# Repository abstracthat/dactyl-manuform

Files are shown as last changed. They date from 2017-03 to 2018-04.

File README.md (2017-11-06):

# The Dactyl-ManuForm Keyboard
This is a fork of the [Dactyl](https://github.com/adereth/dactyl-keyboard), a parameterized, split-hand, concave, columnar, ergonomic keyboard.

Imgur

The main change is that the thumb cluster was adapted from the [ManuForm keyboard](https://github.com/jeffgran/ManuForm) ([geekhack](https://geekhack.org/index.php?topic=46015.0)). The walls were changed to just drop to the floor. The keyboard is paramaterized to allow adjusting the following: 

* Rows: 4 - 6 
* Columns: 5 and up
* Row curvature
* Column curvature
* Row tilt (tenting)
* Column tilt
* Column offsets
* Height

I built a 4x5 version (40% size) for myself. The default has a bit more tenting than the Dactyl. See the following model files for configurations that may be most common:

* [40% size, (4x5)](https://github.com/tshort/dactyl-keyboard/blob/master/things/right-4x5.stl)
* [60% size, (5x6)](https://github.com/tshort/dactyl-keyboard/blob/master/things/right-5x6.stl)

## Assembly

### Generating a Design

**Setting up the Clojure environment**
* [Install the Clojure runtime](https://clojure.org)
* [Install the Leiningen project manager](http://leiningen.org/)
* [Install OpenSCAD](http://www.openscad.org/)

**Generating the design**
* Run `lein repl`
* Load the file `(load-file "src/dactyl_keyboard/dactyl.clj")`
* This will regenerate the `things/*.scad` files
* Use OpenSCAD to open a `.scad` file.
* Make changes to design, repeat `load-file`, OpenSCAD will watch for changes and rerender.
* When done, use OpenSCAD to export STL files

**Tips**
* [Some other ways to evaluate the clojure design file](http://stackoverflow.com/a/28213489)
* [Example designing with clojure](http://adereth.github.io/blog/2014/04/09/3d-printing-with-clojure/)

### Printing
Pregenerated STL files are available in the [things/](things/) directory. 
When a model is generated, it also generates a `.scad` model for a bottom plate. 
This can be exported to a DXF file in OpenSCAD.
The [things/](things/) directory also has DXF files for the bottom plate.
When laser cut, some of the inside cuts will need to be removed. 

This model can be tricky to print. 
It's wide, so I've had problems with PLA on a Makerbot with edges warping. 
This can cause the printer to think its head is jammed. 
Even if it successfully prints, warping can cause problems. 
On one print, the RJ-9 holder was squished, so I had to cut down my connector to fit.

If printed at Shapeways or other professional shops, I would not expect such problems. 

### Thingiverse

[The 4x5 STL left/right pair](https://www.thingiverse.com/thing:2349390) from the [things/](things/) directory is in the thingiverse for public printing

### Wiring

Here are materials I used for wiring.

* Two Arduino Pro Micros
* [Heat-set inserts](https://www.mcmaster.com/#94180a331/=16yfrx1)
* [M3 wafer-head screws, 5mm](http://www.metricscrews.us/index.php?main_page=product_info&cPath=155_185&products_id=455)
* [Copper tape](https://www.amazon.com/gp/product/B009KB86BU)
* [#32 magnet wire](https://www.amazon.com/gp/product/B00LV909HI)
* [#30 wire](https://www.amazon.com/gp/product/B00GWFECWO)
* [3-mm cast acrylic](http://www.mcmaster.com/#acrylic/=144mfom)
* [Veroboard stripboard](https://www.amazon.com/gp/product/B008CPVMMU)
* [1N4148 diodes](https://www.amazon.com/gp/product/B00LQPY0Y0)
* [Female RJ-9 connectors](https://www.amazon.com/gp/product/B01HU7BVDU/)

I wired one half using the traditional approach of using the legs of a diode to form the row connections. 
(I'm not great at soldering, so this was challenging for me.)
For this side, I used magnet wire to wire columns. That worked okay. 
The magnet wire is small enough, it wants to move around, and it's hard to tell if you have a good connection.

Imgur

For another half, I used stripboard for the row connections. 
This allowed me to presolder all of the diodes. 
Then, I hot-glued this in place and finished the soldering of the other diode ends. 
I like this approach quite a lot. 
Connections for the diodes were much easier with one end fixed down. 
On this half, I also used copper tape to connect columns. 
This worked a bit better than the magnet wire for me. 
For a future version, I may try just bare tinned copper wire for columns (something like #20). 
With the stripboard, it's pretty easy keeping row and column connections separate.

Imgur

Note that a telephone handset cable has leads that are reversed, so take this into account when connecting these leads to the controller.

The 3D printed part is the main keyboard. 
You can attach a bottom plate with screws. 
The case has holes for heat-set inserts designed to hold 3- to 6-mm long M3 screws. 
Then, I used wafer-head screws to connect a bottom plate. 
If wires aren't dangling, a bottom plate may not be needed. 
You need something on the bottom to keep the keyboard from sliding around. 
Without a plate, you could use a rubber pad, or you could dip the bottom of the keyboard in PlastiDip.

For more photos of the first complete wiring of v0.4, see [Imgur](http://imgur.com/a/v9eIO).

This is how the rows/columns wire to the keys and the ProMicro
Wire Diagram

#### Alternative row-driven wiring diagram for ProMicro:

NOTE: you also make sure the firmware is set up correctly (ex: change row pins with col pins)

Left Wire Diagram

Left Wire Diagram


### Firmware

Firmware goes hand in hand with how you wire the circuit. 
I adapted the QMK firmware [here](https://github.com/tshort/qmk_firmware/tree/master/keyboards/dactyl-manuform). 
This allows each side to work separately or together. 
This site also shows connections for the Arduino Pro Micro controllers.

## License

Copyright © 2015-2017 Matthew Adereth and Tom Short

The source code for generating the models (everything excluding the [things/](things/) and [resources/](resources/) directories is distributed under the [GNU AFFERO GENERAL PUBLIC LICENSE Version 3](LICENSE).  The generated models and PCB designs are distributed under the [Creative Commons Attribution-NonCommercial-ShareAlike License Version 3.0](LICENSE-models).

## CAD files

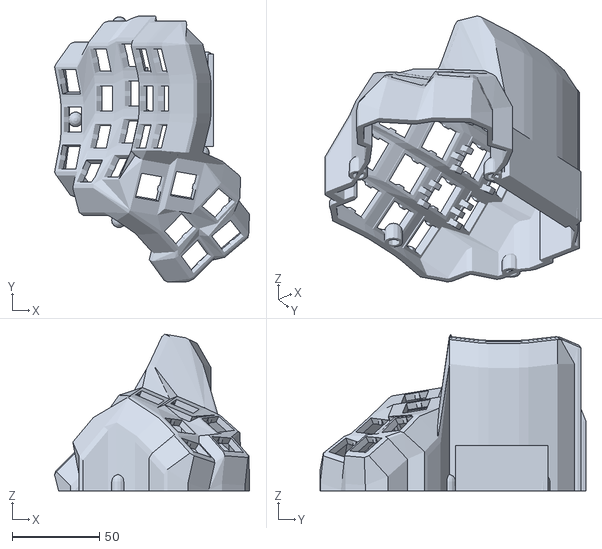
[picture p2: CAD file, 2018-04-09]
things/left.stl
111.8 x 152.3 x 89.8

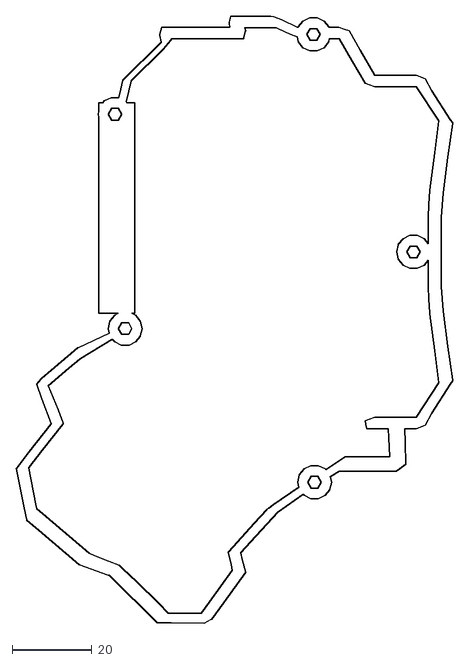
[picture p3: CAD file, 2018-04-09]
things/right-plate.dxf
109.4 x 152.3

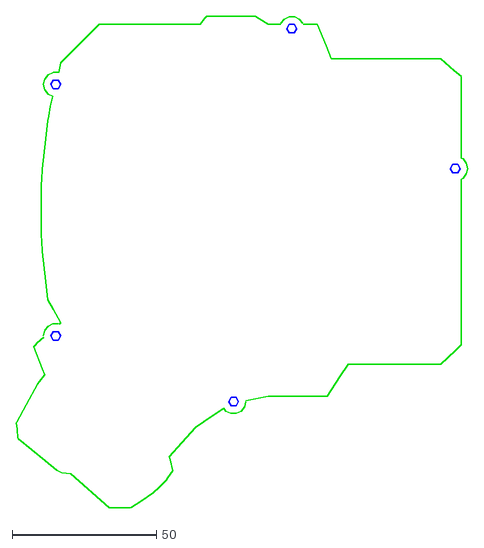
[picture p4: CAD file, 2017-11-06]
things/right-5x6-plate-ready-to-cut.dxf
156.5 x 170.5

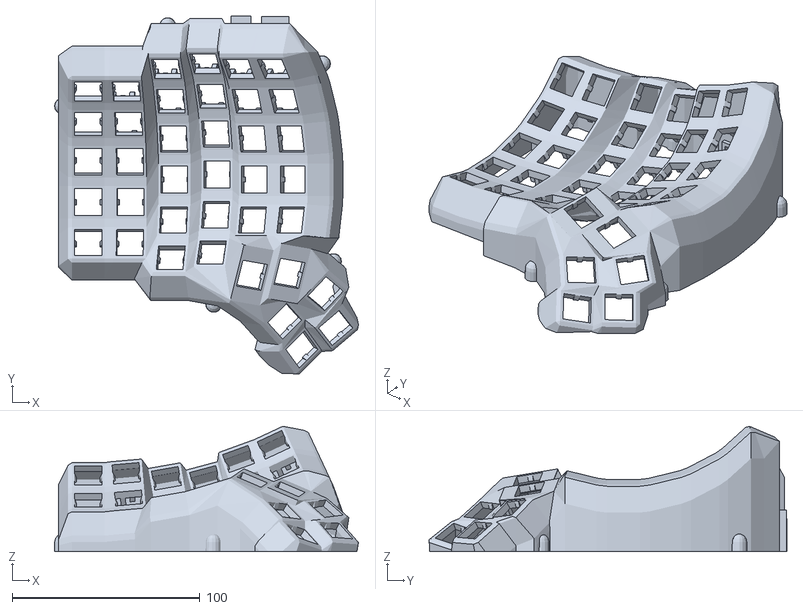
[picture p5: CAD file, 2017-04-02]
things/left-6x6.stl
161.7 x 190.2 x 66.8

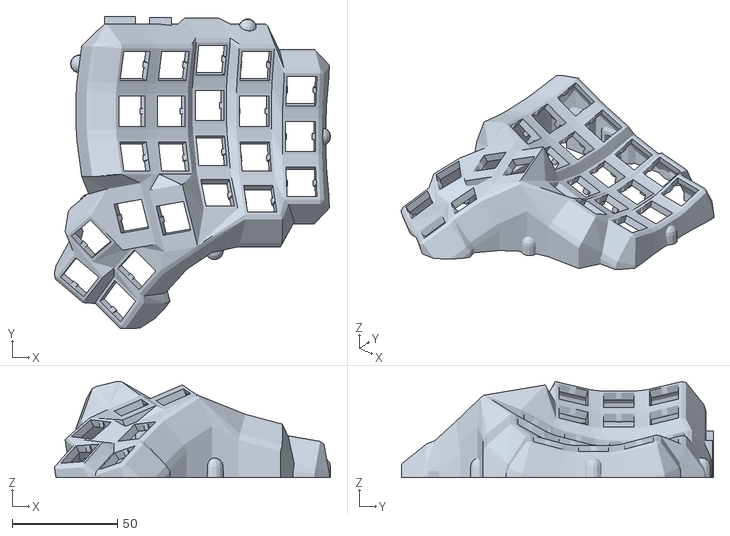
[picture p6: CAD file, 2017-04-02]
things/right-4x5.stl
131.5 x 148.4 x 45.8

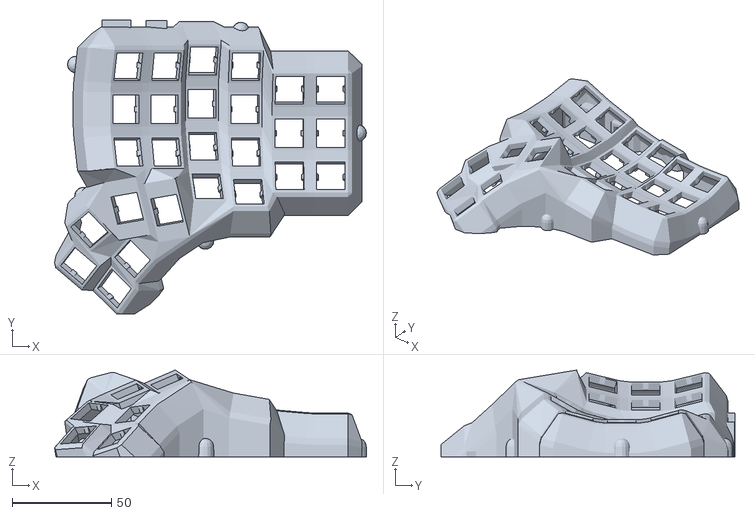
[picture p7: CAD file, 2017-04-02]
things/right-4x6.stl
157.2 x 148.4 x 43.8

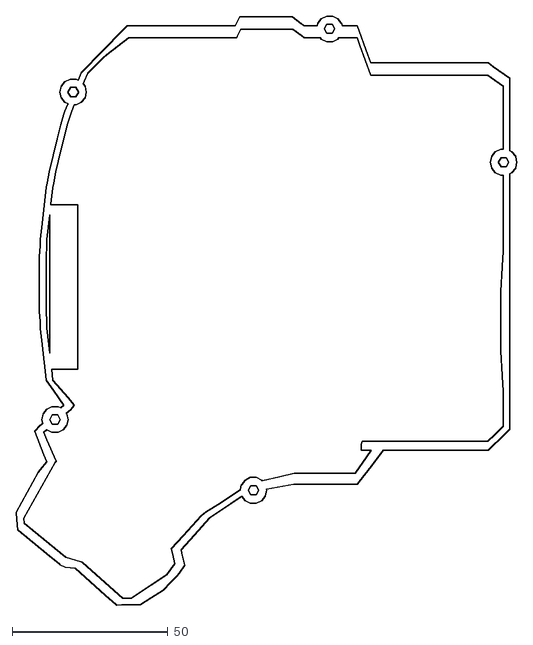
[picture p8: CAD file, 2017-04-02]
things/right-6x6-plate.dxf
160.9 x 189.3

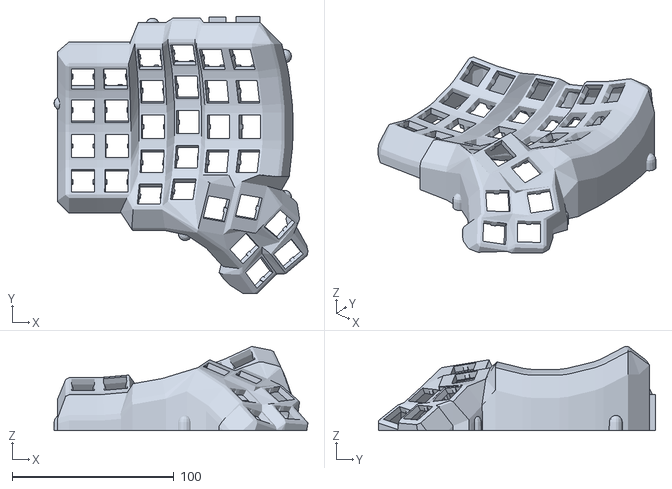
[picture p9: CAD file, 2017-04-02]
things/left-5x6.stl
157.2 x 171.5 x 52.1

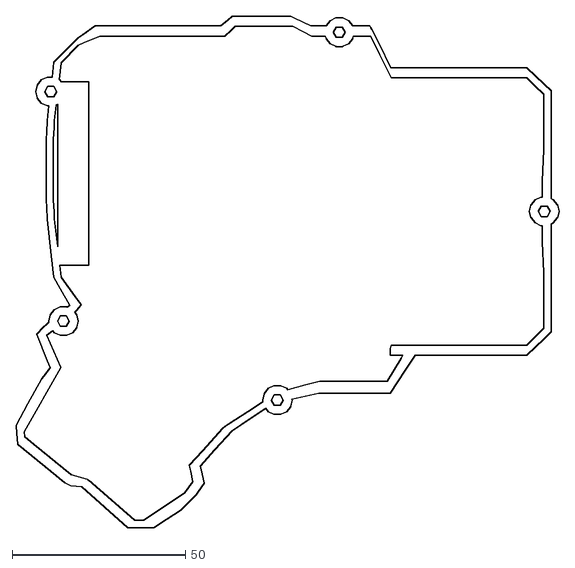
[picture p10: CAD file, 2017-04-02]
things/right-4x6-plate.dxf
156.5 x 147.5

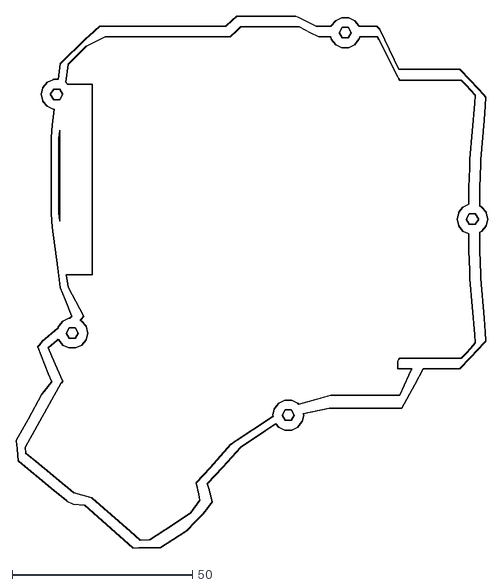
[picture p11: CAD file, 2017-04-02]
things/right-4x5-plate.dxf
130.7 x 147.5

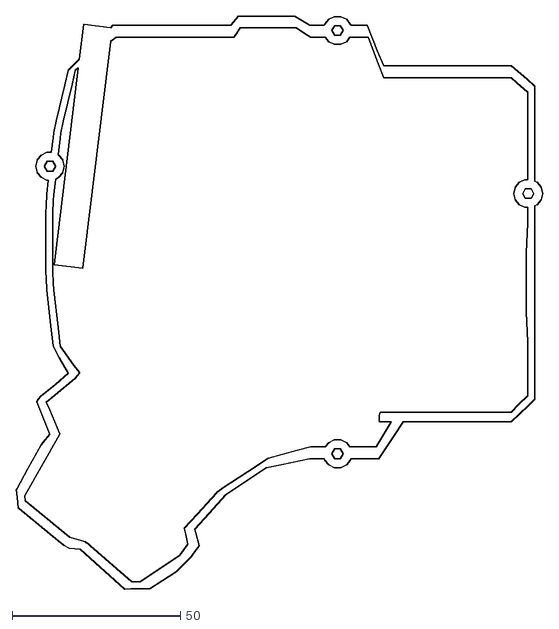
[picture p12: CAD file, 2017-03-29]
things/right-5x6-plate.dxf
156.5 x 170.5

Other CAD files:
things/right.stl
things/left-4x6.stl
things/left-4x5.stl
things/right-5x6.stl
things/right-6x6.stl

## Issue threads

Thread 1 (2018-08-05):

Variable commented out that are used in the code

impaktor, 2018-08-05:
This block:
```clojure
;; Settings for column-style == :fixed
;; The defaults roughly match Maltron settings
;;   http://patentimages.storage.googleapis.com/EP0219944A2/imgf0002.png
;; Fixed-z overrides the z portion of the column ofsets above.
;; NOTE: THIS DOESN'T WORK QUITE LIKE I'D HOPED.
(def fixed-angles [(deg2rad 10) (deg2rad 10) 0 0 0 (deg2rad -15) (deg2rad -15)])
(def fixed-x [-41.5 -22.5 0 20.3 41.4 65.5 89.6])  ; relative to the middle finger
(def fixed-z [12.1    8.3 0  5   10.7 14.5 17.5])
(def fixed-tenting (deg2rad 0))
```
...is commented out in master, and have been since commit a4014a25713525267846ce10188343bf9ddfe6fa. Without it, the code will not run to generate *.scad files.

irrenhaus, 2018-08-14:
Can confirm this @abstracthat.

Just cloned the project and wanted to build it but it turned out that the compiler gave an error.
Luckily this issue was opened, so I was able to resolve it by uncommenting these variables.

impaktor, 2018-08-14:
@irrenhaus I would recommend cloning (or forking) the original dactyl manuform mod instead, which is by @tshort, [here](https://github.com/tshort/dactyl-keyboard)

If you check the commit history, @adereth did the original, @tshort did the Dactyl Manuform, but as a branch of his fork, and this repo just renamed the project to the same name as tshort's branch. Quite confusing. Or at least that's how I interpret it.

This repo is the one that is linked from the geekhack main Dactyl Manuform thread. I think it should link to tshort's repo instead.

(I'll be doing a PLA 3D print of this tomorrow, so we'll see how it turns out.)

irrenhaus, 2018-08-16:
@impaktor Oh thanks a bunch! I think I got to this repository through google, so maybe it's just ranked up higher than the correct repository there.

impaktor, 2018-08-16:
@irrenhaus no problem. I've opened a pull request on tshorts repo, also saving out the swich hole for test printing. It looks to me like what this repo (abstracthat) went for was a 90 degree vertical stagger.

abstracthat, 2018-08-16:
Hi guys. Didn't mean to deceive anyone this is indeed just a fork.

And I haven't printed it but would like to. I don't remember breaking the compile though as I had open scad running while l was tweaking. But it's certainly possible!

It is a very large tenting angle (I use a split Mitosis keyboard on 55degree wood blocks at the moment which I like a lot). I also messed with where the thumb keys sit and I started to move the screws for the bottom plate because they don't line up quite right when the footprint is changed so much for the large tenting.

impaktor, 2018-08-17:
> Hi guys. Didn't mean to deceive anyone this is indeed just a fork.

Yeah, sorry, I didn't mean to come off like I'm implying that.

> It is a very large tenting angle

I wonder if a hollow keyboard has enough friction to the surface to be used at 90-degree angle?

Some of the tweeks I'm aiming to implement on my fork is to re-import the original TRRS jack, instead of the RJ9 connector. I'm currently just where I need to figure out how to move the TRRS hole to where I want it.

Also, Alps/Matias switch holes would be nice, which is also something I'll play around with.

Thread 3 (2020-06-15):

types of switches

shiftux, 2020-06-15:
hello,
this project looks amazing! thanks for all the work! - i'm planning on making one!
i'd like to understand the compatibility with different switch manufacturers...
thinking of Cherry, Kailh, Gateron, ...
Could someone make a statement about what would fit?
or is it possible to customize the switch sockets (like explained here https://github.com/adereth/dactyl-keyboard/issues/56#issuecomment-376463735) ?

thanks for your insights

BobLoblaw5, 2020-06-21:
I just built one using gateron browns and I know cherry switches will work as well.  Not as familiar with Kailh but I would think that any Mx style switch should work.

shiftux, 2020-07-07:
the answer here is yes, they do work.
but indeed you need to modify the switch sockets, you'll want to remove the "side-nub" in the clojure files

Closed 2020-07-07.

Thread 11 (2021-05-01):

Kailh incompatibility

flowswitch, 2021-05-01:
A little warning for fellow builders planning to use Kailh switches: the side locking tabs are incompatible with Kailhs (those have no side notches matching them). A switch could be forced into position, but it will tend to jump out. Either remove the tabs from the model before printing or cut them with shears after (that was my case, discovered the problem after printing).
Other types of switches I’ve tested are Gateron and Everglide - both fits perfectly (they follow Cherry MX shape I guess).

suryanisaac, 2021-07-27:
Hey! Thanks for the heads up - I was planning to use Kailh switches.

Do you know of any forks/versions without the tabs?

flowswitch, 2021-07-27:
Unfortunately no. Found the problem after printing so the question was how to fix the already printed part.

suryanisaac, 2021-07-28:
Thank You, I just found a few forks that have already implemented it

Sorcecoder, 2024-12-18:
I object, I was able to use Kailhs just fine, had to remove any Fuzzy finish and stick with the boring standard though since the holes are counted as outer wall.

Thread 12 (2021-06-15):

Printing Service claims that halves would break

jnnks, 2021-06-15:
My local printing service claims that the STL files contain errors which would result in the halves breaking.
They also sent some images:
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

What is your opinion on this?
It's about the 5x6 variant from the things/ foler

Closed 2021-08-04.

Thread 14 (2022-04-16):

Adding leds makes one half urensponsive

Spamm3r, 2022-04-16:
So I made 6x6 manuform and it was challenging built (so far :P) and I want to add leds strips to each of halves. So I go vcc and gnd from pro micro (master) and on slave i got vcc and gnd from board after connecting rj9. RGB pin was set to d3 and then by me to d2. Overall leds are working on first half, on second one they are working but no key presses are "recorded". I tried lowering number of leds etc but nothing works.
In qmk I have set that I have 30 leds and 15 on each half. I set left to master, tried to carry out signal dOut but no luck. Without leds it works 100%.

Spamm3r, 2022-04-18:
I have found the issue, rj9. Dunno if particular mine cable and ports were faulty but totally switching to trrs, solved problem and now everything works. Maybe it is worth it that for better pertormance with leds it is suggested to use trrs serial connection. Thanks for great keeb man!

Closed 2022-04-18.

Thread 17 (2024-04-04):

Guide and Readme have different BOMs

KosmicKatXV, 2024-04-04:
Good afternoon, I am compiling all the materials I require for building this keyboard, however I have discovered the guide uses really different materials from the ones shown in the Readme.

WolfIcefang, 2024-04-04:
Hello KosmicKatXV, I am currently in the final stretch of my school semester. I'll be able to start updating this repo again starting April 17th. Definitely hold off on buying parts. I don't know if I've uploaded the latest build guide and the readme parts list is going to get deleted. Thanks for your patience!

WolfIcefang, 2024-04-04:
If you got emailed saying "wait until April 17th" that is incorrect. I thought this was my Dactyl fork; it is not. My apologies.

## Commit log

2017-03-13 Improvements (#3)
    * Start at Kludgy maltron style spacing
    * Thumb and pinky tweaks
    * Fix keyboard-z-offset problem
    * Tweaks for a shorter-height version
    * Add wall-thickness parameter
    * Change hex-spacers to screw-inserts
    * Adjust height
    * Fix usb-cutout size and alignment
    * Adjust teensy-holder
    * Clean out junk
    [repl.scad, repl.stl, right-4x5.scad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]
2017-03-17 Left wall (#4)
    * Add screw insert to hold the teensy
    * Allow wider wall spacings for more internal room
    * Fix the clunky thumb connections
    * Enable the teensy holder for all styles
    [right-4x5.stl, right-4x6.stl, right-5x6.stl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]
2017-03-23 General updates (#5)
    * Add wire posts
    * Add wire posts for the thumb.
    * Move teensy screw insert back
    * Thicken wire posts
    * Add model
    * Add in a projection for the bottom plate
    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
    [right-4x5.stl]
2017-03-24 Readd/fix plates
2017-03-29 Updates for v0.4
    [left-4x5.stl, left-5x6.stl, right-4x5-plate.dxf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]
2017-04-02 Move Teensy holder away from edge
2017-04-02 Add another screw insert
2017-04-02 Adjust screw inserts
2017-04-02 Teensy holder tweak
2017-04-02 Add CAD files
    [left-4x5.stl, left-4x6.stl, left-5x6.stl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]
2017-06-12 Added wiring diagram for 4x5 to Pro Micro (#9)
2017-11-06 Add ready to cut dxf for 5x6, and new wire diagrams (#10)
    * Add ready to cut dxf file for 5x6
    * Add new wire diagram
    Hopefully people find it helpful
    [right-5x6-plate-ready-to-cut.dxf]
2018-04-09 Add rendered stl files
    [left.stl, right-plate.dxf, right.stl]
